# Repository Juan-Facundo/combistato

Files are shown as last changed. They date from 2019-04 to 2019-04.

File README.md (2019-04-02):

# COMBISTATO :smiley:

Es un circuito electrónico basado en [arduino](https://es.wikipedia.org/wiki/Arduino) para que haga la función de termostato doble accion para controlar frio / calor.

Esta diseñado con un arduino nano con atmega 328.

Su funcionamiento básico es de comandar dos salidas que manejen equipos de frio y calor para mantener la temperatura de lo que se desea controlar. Para ello se puede ajustar:
* Punto de ajuste de trabajo (set point)
* Ajuste de la ventana de accion (histeresis)
* Retardo de reconeccion para frio y calor separados (algunos equipos lo requieren)
* Error: ajuste de calibracion para eliminar el posible error de la medicion.

La presición del aparato depende mayormente del sensensor. En este caso, el fabricante del 18b20 dice que puede tener un error de 0,5 grados centígrados. Otros sensores, se verá.
Tiene la funcion de guardar los valores de ajustes en la memoria eeprom para que sean legibles luego de una desconexión de la alimentación.
Posee la posbilidad de habilitar o deshabilitar el regitro en consola serial.

## La idea:
La idea es poder realizar con poco dinero, una circuito util, de gran versatilidad y bastante fiable.
Se usara sensor digital de tempertatura [ds18b20](https://datasheets.maximintegrated.com/en/ds/DS18B20.pdf), pero puede usarse cualquiera.
En la salida tendrá un modulo de relé doble, con capacidad de 10A. En su idea original, fue diseñado para controla un motocompresor de refrigeración.

## La electrónica:
* Arduino [nano](https://www.arduino.cc/en/Guide/ArduinoNano) con atmega 328
* modulo de relé de 5v con contacto para 10A
* teclado matricial 4x4
* pequeña fuente de alimentación 
* resistores varios
* display [lcd-16x02](https://www.engineersgarage.com/electronic-components/16x2-lcd-module-datasheet)

#### Para hacer:

- Conectar un _buzzer_ y agregar el codigo que falta para las alarmas.
- Desarrollar el codigo para poder configurarlo como dos termostatos separados.

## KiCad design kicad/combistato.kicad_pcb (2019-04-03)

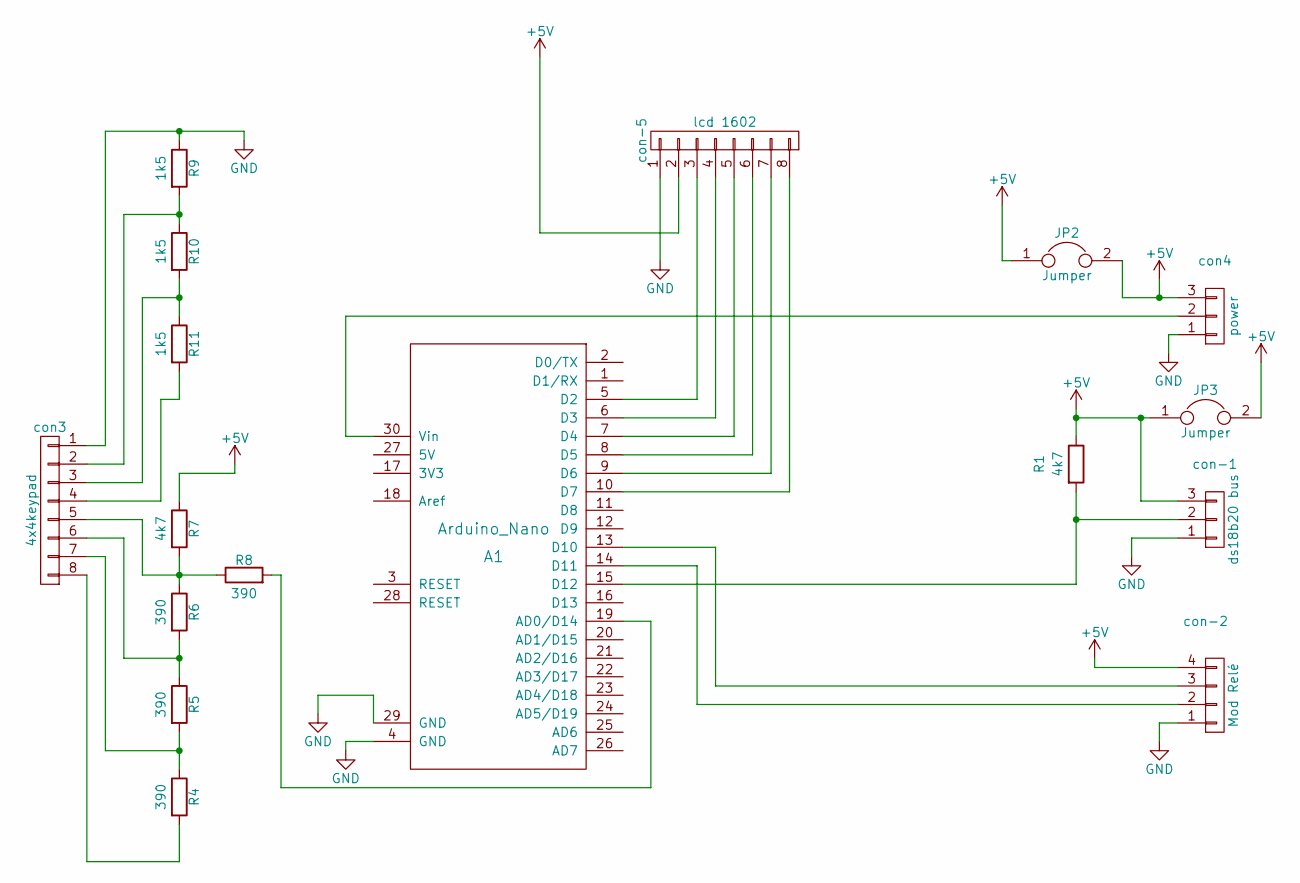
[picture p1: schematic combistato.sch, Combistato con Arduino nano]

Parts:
A1: Arduino_Nano; arduino_nano
JP2, JP3: Jumper; R_Axial_DIN0411_L9.9mm_D3.6mm_P12.70mm_Horizontal
R1, R7: 4k7; R_Axial_DIN0411_L9.9mm_D3.6mm_P12.70mm_Horizontal
R4, R5, R6, R8: 390; R_Axial_DIN0411_L9.9mm_D3.6mm_P12.70mm_Horizontal
R9, R10, R11: 1k5; R_Axial_DIN0411_L9.9mm_D3.6mm_P12.70mm_Horizontal
con3: 4x4keypad; Pin_Header_Angled_1x08
con4: power; Pin_Header_Angled_1x03
con-1: ds18b20 bus; Pin_Header_Angled_1x03
con-2: Mod Relé; Pin_Header_Angled_1x04
con-5: lcd 1602; Pin_Header_Angled_1x08

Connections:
+5V: JP2.1, JP2.2, JP3.1, JP3.2, R1.1, R7.1, con4.3, con-1.3, con-2.4, con-5.2
GND: A1.4 (GND), A1.29 (GND), R9.1, con3.1, con4.1, con-1.1, con-2.1, con-5.1
unnamed: A1.5 (D2), con-5.3
unnamed: A1.6 (D3), con-5.4
unnamed: A1.7 (D4), con-5.5
unnamed: A1.8 (D5), con-5.6
unnamed: A1.9 (D6), con-5.7
unnamed: A1.10 (D7), con-5.8
unnamed: A1.13 (D10), con-2.3
unnamed: A1.14 (D11), con-2.2
unnamed: A1.15 (D12), R1.2, con-1.2
unnamed: A1.19 (AD0/D14), R8.2
unnamed: A1.30 (Vin), con4.2
unnamed: R4.1, R5.2, con3.7
unnamed: R4.2, con3.8
unnamed: R5.1, R6.2, con3.6
unnamed: R6.1, R7.2, R8.1, con3.5
unnamed: R9.2, R10.1, con3.2
unnamed: R10.2, R11.1, con3.3
unnamed: R11.2, con3.4

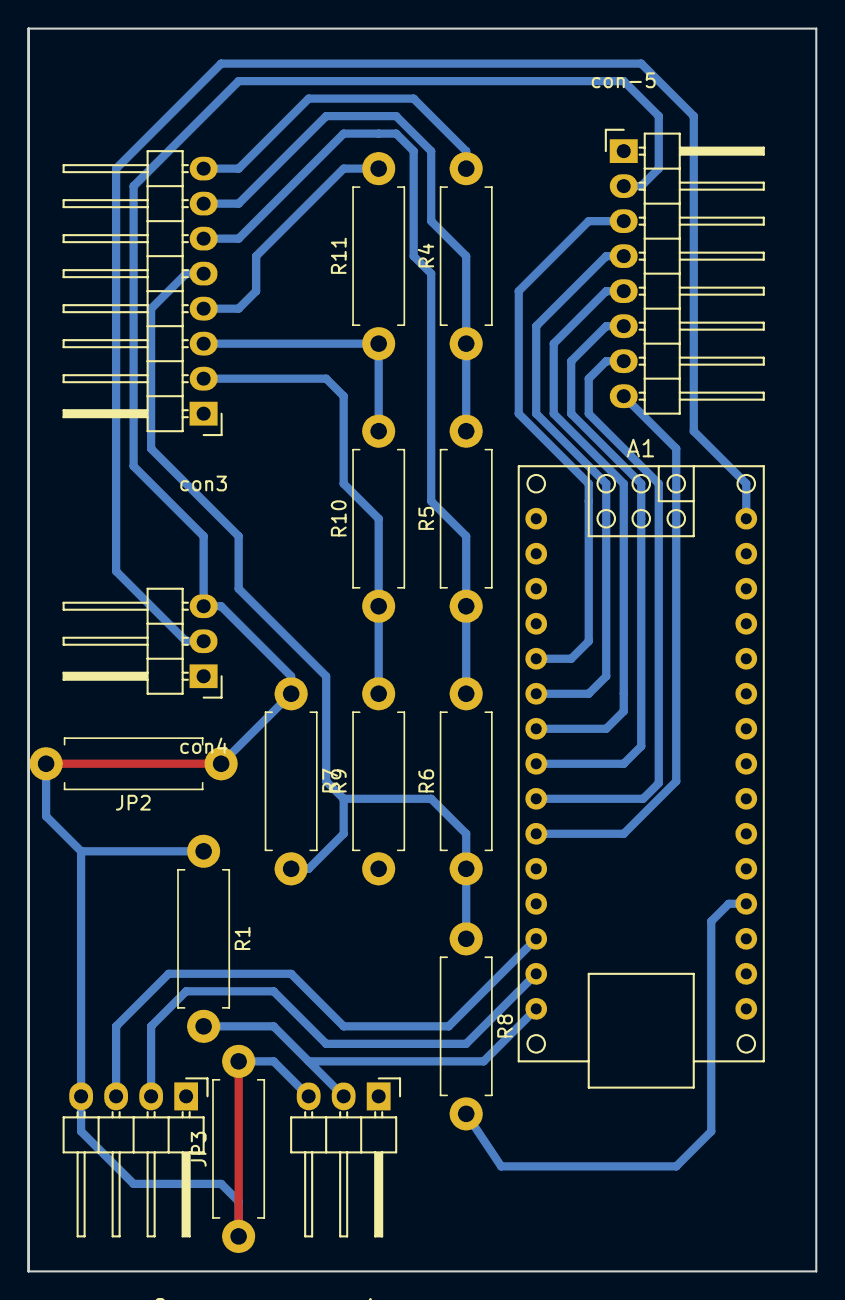
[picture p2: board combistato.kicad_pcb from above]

Board: 2 copper layers, 57.1 x 90.2 mm, 17 parts (0 on the bottom side), 20 nets.

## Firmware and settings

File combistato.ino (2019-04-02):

// COMBISTATO PROGRAMABLE, FRIO CALOR O DOBLE TERMOSTATO
// por Facundo Suarez
// 2019

#include <EEPROM.h>
#include <TimeLib.h>
#include <OneWire.h> //temp
#include <DallasTemperature.h> //temp
#include <LiquidCrystal.h> //lcd

#define ONE_WIRE_BUS 12
OneWire oneWire(ONE_WIRE_BUS);
DallasTemperature sensors(&oneWire);
DeviceAddress termo1 = {0x28, 0xFF, 0xA0, 0xE1, 0xC1, 0x17, 0x05, 0xF8};
DeviceAddress termo2 = {0x28, 0xFF, 0x4D, 0xC3, 0x82, 0x17, 0x04, 0x32};

// definiendo variables de almacenamiento 
float datos[3][5]; // para amacenar la lectura de cada sensor, su maxima y su minima
float trabajo[5]; // para almacenar ajustes de trabajo
float alarmas[5]; // almacenar alarmas.
byte CIERRE=1;

// variables de registro en serial y lcd
// Los siguientes valores seran configurables en nuevas versiones
int serialLog=5;   // sengundos de intervalo de registro de consola
long serialSegPre;  // contador tiempo previo registro en consola
int lcdLog=1;   // sengundos de intervalo de registro en display
long lcdSegPre;  // contador tiempo previo registro en display
byte PS = 0; // control de rutina de regitro en consola serie

//control de retardo de accion de combistato
long ctlRetF;
long ctlRetC;

// variables de control de chiller
int preFrio=15;    //segundos de marcha de ventilador antes que el compresor
int postFrio=200;  // sengundos de ventilador del condensador despues de parar el compresor
int demanda=300;  // sengundos de marcha por demanda antes de parar por temperatura
long preVent;       // para almacenar el tiempo de control de ventilacion pre frio
long postVent;       // para almacenar el tiempo de control de ventilacion post frio
long actDem;      // para almacenar el tiempo de inicio de la marcha por demanda

// para el lector de teclado..
int niveles[16]={12,88,155,218,254,299,340,380,402,432,460,487,502,524,542,563};
int teclas[16]={1,2,3,11,4,5,6,12,7,8,9,13,15,0,16,14};
int codigo=0;

// textos de los menus..
String CFGs[5]={"CONFIGURAR","1.Guardar Vals.","2.Guardar Alarmas","3.Cambiar sensor","4 -> ..."};
String ALs[5]={"ALARMAS","1.Baja: ","2.Baja ?","3.Alta:","4.Alta ?"};
String TRBJ[5]={"TRABAJO","1.Ajuste:","2.Ventan:","3.Demora:","4.Error :"};

/*
para control de pantallas
0 -> pantalla normal
1 -> pantalla de ajustes
2 -> pantalla de alarmas
3 -> pantalla de configurar
4 -> pantalla de Acerca de ..
*/
byte pantalla = 0;

int lcdClear = 120;
long actLCD;

int estado = 0;
String msj="";

int DisInd = 0;
int controlLed = 1;
int cantSens = 2;

int CLAVE;

/*
 The circuit:
 * LCD RS pin to digital pin 2
 * LCD En pin to digital pin 3
 * LCD D4 pin to digital pin 4
 * LCD D5 pin to digital pin 5
 * LCD D6 pin to digital pin 6
 * LCD D7 pin to digital pin 7
*/
LiquidCrystal lcd(2, 3, 4, 5, 6, 7);

byte sagitario[8] = { 0b00000000,0b00000111,0b00000011,0b00010101,0b00001000,0b00010100,0b00000000,0b00000000 };
byte grado[8] = { 0b00001100,0b00010010,0b00010010,0b00001100,0b00000000,0b00000000,0b00000000, 0b00000000 };
void setup(){ 

  /*  leer datos de la eeprom
    Las direcciones de la eeprom seran:
    AJUSTES:
    -  (1) y (2)  ->  punto de ajuste   [entero x10]
    -        (3)  ->  ancho de la ventana de histeresis [byte x10]
    -        (4)  ->  retardo entre acciones, en minutos [byte x1]
    -  (5) y (6)  ->  desvio o error de sensor [x10, entero]
    
    ALARMAS:
    -  (10)       ->  Alarma de Baja temperatura [x10, entero]
    -  (11)       ->  Alarma de baja activa o no [1 o 0]
    -  (12)       ->  Alarma de Alta temperatura [x10, entero]
    -  (13)       ->  Alarma de Alta activa o no [1 o 0]

    OTROS
    -  (21) y (22)  -> clave para cambiar ajustes

  */
  byte EEdir;
  int EEvalor;

  trabajo[1] = (float)(( EEPROM.read(1) << 8 ) + EEPROM.read(2))/(float)10; //Ajuste
  trabajo[2] = (float) EEPROM.read(3)/(float) 10; //histeresis
  trabajo[3] = (float) EEPROM.read(4); // retardo
  trabajo[4] = (float)((EEPROM.read(5) << 8)  + EEPROM.read(6))/(float)10; //error
  
  alarmas[1] = (float) EEPROM.read(10)/(float) 10; //ajuste
  alarmas[2] = (float) EEPROM.read(11); // activa
  alarmas[3] = (float) EEPROM.read(12)/(float) 10; //ajuste
  alarmas[4] = (float) EEPROM.read(13); // activa
  CLAVE = (int)(( EEPROM.read(21) << 8 ) + EEPROM.read(22));
  //CLAVE=3312;
  // fin de lectura de eeprom

  trabajo[0]=-237; //evitar impresion en lcd
  alarmas[0]=-237; //evitar impresion en lcd

  pinMode(A0,INPUT); // para leer el teclado
  pinMode(8,OUTPUT); // control de ventilador de condensador
  pinMode(9,OUTPUT); // control de motocompresor
  digitalWrite(8,LOW);
  digitalWrite(9,LOW);
  pinMode(LED_BUILTIN,OUTPUT);
  pinMode(10,INPUT_PULLUP); // ingreso de evento desde el control de fermentadores

  lcd.begin(16, 2);
  lcd.createChar(2, sagitario);
  impLinea(0,0,"  Sagitario",-237,0);
  impLinea(1,0,"Combistato plus",-237,0);
  
  delay(3000);

  sensors.begin();
  sensors.setResolution (termo1, 12);
  sensors.setResolution (termo2, 12);

} 

void loop() {

  long segAct = now();
  char c = '.' ;
  String comando ="" ;
  String numero ="" ;  

  int tecla = leerTecla();

  if (codigo == 980) buscaSensor();
  if (codigo == 157) {
    Serial.begin(19200);
    PS=2;
    impLinea(1,0,"Serial SI",PS,11);
    codigo=0;
  }
  if (codigo == 156) {
    Serial.begin(19200);
    PS=1;
    impLinea(1,0,"Serial SI",PS,11);
    codigo=0;
  }
  if (codigo == 155) {
    impSerie("Registro en consola desactivado...\n",-237,1);    
    Serial.end();
    PS=0;
    impLinea(1,0,"Serial NO",-237,0);
    codigo=0;
  }
  if (codigo == 914) {
    impLinea(1,0,"",CLAVE,0);
    Serial.println(CLAVE);
    codigo=0;
  }
  if (codigo==915 && CIERRE==0) {
    impLinea(0,0,"nueva:",-237,0);
    CLAVE=ingrVal("clave:");
  }    
  if (codigo == 916 && CIERRE==0) {
    intAeeprom(21,CLAVE);
    impLinea(1,0,"Perfectirijillo",-237,0);
    codigo=0;
  }
  
  if (pantalla==1 && tecla>0 && tecla<5) trabajo[tecla] = ingrVal(TRBJ[tecla]);
  if (pantalla==2 && tecla>0 && tecla<5) alarmas[tecla] = ingrVal(ALs[tecla]);
  if (pantalla==3 && tecla==1) {
    intAeeprom(1,trabajo[1]*10);
    byteAeeprom(3,trabajo[2]*10);
    byteAeeprom(4,trabajo[3]);
    intAeeprom(5,trabajo[4]*10);
    impLinea(1,0,"Grabado a EEPROM",-237,0);
    delay(2000);
  }
  if (pantalla==3 && tecla==2) {
    byteAeeprom(10,alarmas[1]*10);
    byteAeeprom(11,alarmas[2]);
    byteAeeprom(12,alarmas[3]*10);
    byteAeeprom(13,alarmas[4]);
    impLinea(1,0,"Grabado a EEPROM",-237,0);
    delay(2000);
  }

  if (tecla==11) pantalla = 1;
  if (tecla==12) pantalla = 2;
  if (tecla==13) pantalla = 3;
  if (tecla==14) {
    lcd.clear();
    pantalla = 0;
  }

//   = = = = I N I C I O = = = = 
// bucle de impresion en lcd y control

  if(segAct - lcdSegPre >= lcdLog) { 

    sensors.requestTemperatures(); // Send the command to get temperatures
    datos[1][0] = sensors.getTempC(termo1);
    datos[2][0] = sensors.getTempC(termo2);
    byte ind;
    lcdSegPre = segAct;

// rutina para identificar y registrar maximo y minimo
    for (int i=1; i <= cantSens; i++){
      if (datos[i][1] < datos[i][0]){ // T max
        datos[i][1]=datos[i][0];
        datos[i][2]=now();
        impLinea(1,0,"Max:",datos[i][1],5);
      }

      if (datos[i][0] != -127) {
        if ((datos[i][3] > datos[i][0]) || (datos[i][3] == 0)){ // T min
          datos[i][3]=datos[i][0];
          datos[i][4]=now();
          impLinea(1,0,"Min:",datos[i][3],5);
        }
      }
    }

// Pantallas
    if (pantalla==1){
      if (DisInd == 5) DisInd = 0;
      impLinea(0,0,TRBJ[DisInd],trabajo[DisInd],10);
      if (DisInd == 4) ind = 0; else ind=DisInd+1;
      impLinea(1,0,TRBJ[ind],trabajo[ind],10);
      DisInd += 1;
    }

    if (pantalla==2){
      if (DisInd == 5) DisInd = 0;
      impLinea(0,0,ALs[DisInd],alarmas[DisInd],11);
      if (DisInd == 4) ind = 0; else ind=DisInd+1;
      impLinea(1,0,ALs[ind],alarmas[ind],11);
      DisInd += 1;
    }

    if (pantalla==3){
      if (DisInd == 5) DisInd = 0;
      impLinea(0,0,CFGs[DisInd],-237,0);
      if (DisInd == 4) ind = 0; else ind=DisInd+1;
      impLinea(1,0,CFGs[ind],-237,0);
      DisInd += 1;
    }

    if (pantalla==0){
      impLinea(0,0,"T:",datos[1][0],2);
    }

    //  = = = C O M B I S T A T O = = = 
    // control de frio - enfriar
    long TPO=trabajo[3]*60;
    if(datos[1][0]!=-127){
      if (!digitalRead(8)) {
        if (datos[1][0] >= (trabajo[1]+trabajo[2])) {
          if(segAct-ctlRetF < TPO) {
            msj="frio";
            impSerie("Frio demorado...\n",237,2);
             if(controlLed<0) msj="-"+String(TPO+ctlRetF-segAct)+"-";
          }
          if(segAct-ctlRetF >= TPO) {
            msj="FRIO";
            impSerie("Frio iniciado...\n",-237,1);
            digitalWrite(8, HIGH);
          }
        }
      }
      // control de frio - dejar de enfriar
      if ((datos[1][0] <= trabajo[1]) && digitalRead(8)) {
        digitalWrite(8, LOW);
        impSerie("Frio detenido...\n",-237,1);
        ctlRetF = segAct;
      }
      // control de calor - dejar de calentar
      if ((datos[1][0] >= trabajo[1]) && digitalRead(9)) {
        digitalWrite(9, LOW);
        impSerie("Calor detenido...\n",-237,1);
        ctlRetC = segAct;
      }
      // control de calor - calentar
      if(!digitalRead(9)) {    
        if (datos[1][0] <= (trabajo[1]-trabajo[2])) {
          if(segAct-ctlRetC < TPO) {
           msj="calor";
           impSerie("Calor demorado...\n",-237,2);
           if(controlLed<0) msj="-"+String(TPO+ctlRetC-segAct)+"-";
          }
          if(segAct-ctlRetC >= TPO) {
            msj="CALOR";
            impSerie("Calor iniciado...\n",-237,1);
            digitalWrite(9, HIGH);
          }
        }
      }
      if (!digitalRead(8) && !digitalRead(9) &&
         msj!="calor" && msj!="frio" &&
         !msj.startsWith("-")) {
           msj="";
         }
      if(pantalla==0) impLinea(0,11,msj,-237,10);
    }
    else {
      impLinea(0,0,"   ERROR",-237,10);
      impLinea(1,0," en sensor",-237,10);
    }

//    Serial.println(msj);
        //  = = F I N    C O M B I S T A T O = = 

    controlLed = -controlLed;
    lcd.setCursor(9, 0);
    if (controlLed > 0) {
      if(pantalla==0) lcd.print(" ");
      digitalWrite(LED_BUILTIN, LOW);
    }
    else {
      if(pantalla==0) lcd.write(2);
      digitalWrite(LED_BUILTIN, HIGH);
    }
  }

//   = = = = F I N = = = = 
// de bucle de impresion en lcd y control


 //   = = = = I N I C I O = = = = 
// rutina de registro en consola Serial
   if(segAct - serialSegPre >= serialLog) {

     if(pantalla==0) {
       impLinea(1,0,"M:",datos[1][1],2);
       impLinea(1,8,"m:",datos[1][3],10);
     }

  if(PS>=1) {
    Serial.print(now());
    for (int i=1; i <= cantSens; i++){
      Serial.print(" - Temp");
      Serial.print(i);
      Serial.print(": ");
      Serial.print(datos[i][0]);
      Serial.print("C");
      }
    }
    Serial.println();  
  serialSegPre = segAct;
  }

//   = = = = F I N = = = = 
// fin de rutina registro en consola

}

void impLinea (int lin, int col, String msj, float dato, int col2) {
  lcd.setCursor(col, lin);
  lcd.print("                ");
  lcd.setCursor(col, lin);
  lcd.print(msj);
  if (dato!=-237) {
    lcd.setCursor(col2, lin);
    lcd.print(dato);
  }
}  
// funcion para grabar en eeprom un entero (2 bytes)
void intAeeprom(byte EEdir, int EEvalor) {
  EEPROM.write(EEdir, highByte(EEvalor));
  EEPROM.write(EEdir + 1, lowByte(EEvalor));
}
// funcion para grabar en eeprom un byte
void byteAeeprom(byte EEdir, byte EEvalor) {
  EEPROM.write(EEdir, EEvalor);
}

int leerTecla() {
  int teclado = analogRead(A0); // -- inicio comandos por teclado matricial 4x4 --
  if (teclado < 1000) {
    for(int t=0; t<16; t++) {
      if(abs(teclado - niveles[t]) < 5) {
        Serial.print (teclado);
        Serial.print (" -> ");
        Serial.println (teclas[t]);
        lcd.setCursor(14, 0);
        lcd.print(teclas[t]);
        delay(200);
        
        if (pantalla==0) {
          codigo=codigo*10+teclas[t];
          if (codigo > 999) {
            if(codigo==CLAVE) {
              CIERRE=0;
              impLinea(1,0,"Desbloqueado",-237,7);
            }
            else impLinea(1,0,"Codigo:",codigo,8);
            codigo=0;
          }
        }

        while(analogRead(A0) < 1000) delay(100);
        return teclas[t];
      }
    }
  }// -- fin comandos por teclado matricial 4x4 --
}

float ingrVal(String var) {
  float entrada=0;
  impLinea(0,0,var,-237,0);
  impLinea(1,0,"valor:",entrada,7);
  long SALIR=now();
  while(SALIR>0){
    int tecla=leerTecla();
    if(tecla<10) {
      entrada = entrada*10+tecla/(float)10;
      impLinea(1,0,"valor:",entrada,7);
    }
    if(tecla==15) {
      entrada=-entrada;
      impLinea(1,0,"valor:",entrada,7);
    }
    if(tecla==16) {
      entrada=0;
      impLinea(1,0,"valor:",entrada,7);
    }
    if(tecla==11) impLinea(0,0,"Confirma?",-237,0);
    if(tecla==14) {
      break;
    }
    if(now()-SALIR>30) {
      entrada=-237;
      break;
    }
  }
  return entrada;
}

void guarVals(){
}
// funcion de impresion en consola, para usarlo:
// a es texto, b float y c nivel de registro
void impSerie(String a, float b, byte c){
  if(PS>=c) {
    Serial.print(a);
    if(b!=-237) {
      Serial.print(b);
      Serial.println();
    }
  }
}

void buscaSensor(void) {
  if(PS==0) Serial.begin(19200);
  impLinea(0,0,"Direccion en",-237,7);
  impLinea(1,0,"consola serie",-237,7);
  delay (2000);
  byte i;
  byte present = 0;
  byte data[12];
  byte addr[8];
  
  Serial.print("Buscando sensores...\n\r");
  while(oneWire.search(addr)) {
    Serial.print("encontrados con direccion:\n\r");
    for( i = 0; i < 8; i++) {
      Serial.print("0x");
      if (addr[i] < 16) {
        Serial.print('0');
      }
      Serial.print(addr[i], HEX);
      if (i < 7) {
        Serial.print(", ");
      }
    }
    if ( OneWire::crc8( addr, 7) != addr[7]) {
        Serial.print("CRC no valida!\n");
        return;
    }
  }
  Serial.print("\n\rEs todo.\r\n");
  oneWire.reset_search();
  if(PS==0) Serial.end();
  codigo=0;
  return;
}

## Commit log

2019-04-02 editando el readme
2019-04-02 agregando librerias para kicad
    [combistato.kicad_pcb, combistato.sch]
2019-04-02 edicion de kicad para diagrama de circuito
    [combistato.sch]
2019-04-03 trabajo en pcb, circuitos, etc
    [combistato.sch]
2019-04-03 trabajando en pcb, esquema de circuito y otros
    [combistato.kicad_pcb, combistato.sch]
